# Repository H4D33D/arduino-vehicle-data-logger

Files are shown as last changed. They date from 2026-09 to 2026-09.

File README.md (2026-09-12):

# Arduino OBD-II Vehicle Data Logger

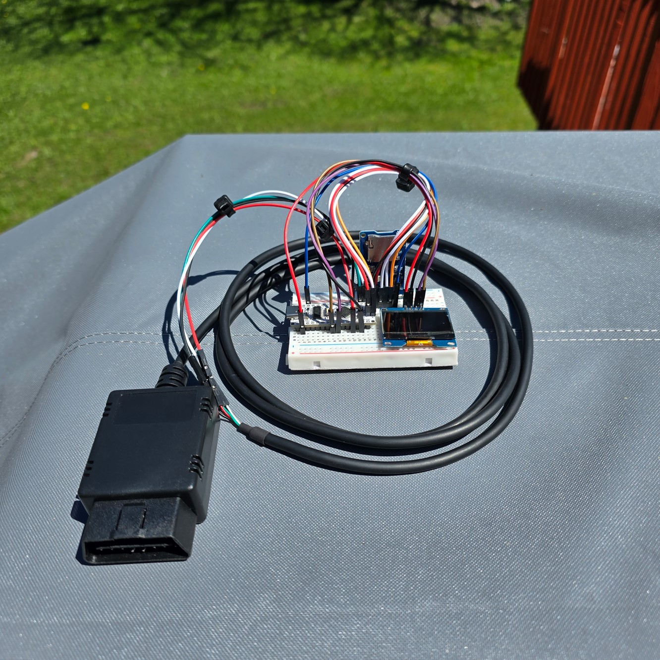
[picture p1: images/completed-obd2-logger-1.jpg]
Completed Arduino OBD-II data logger


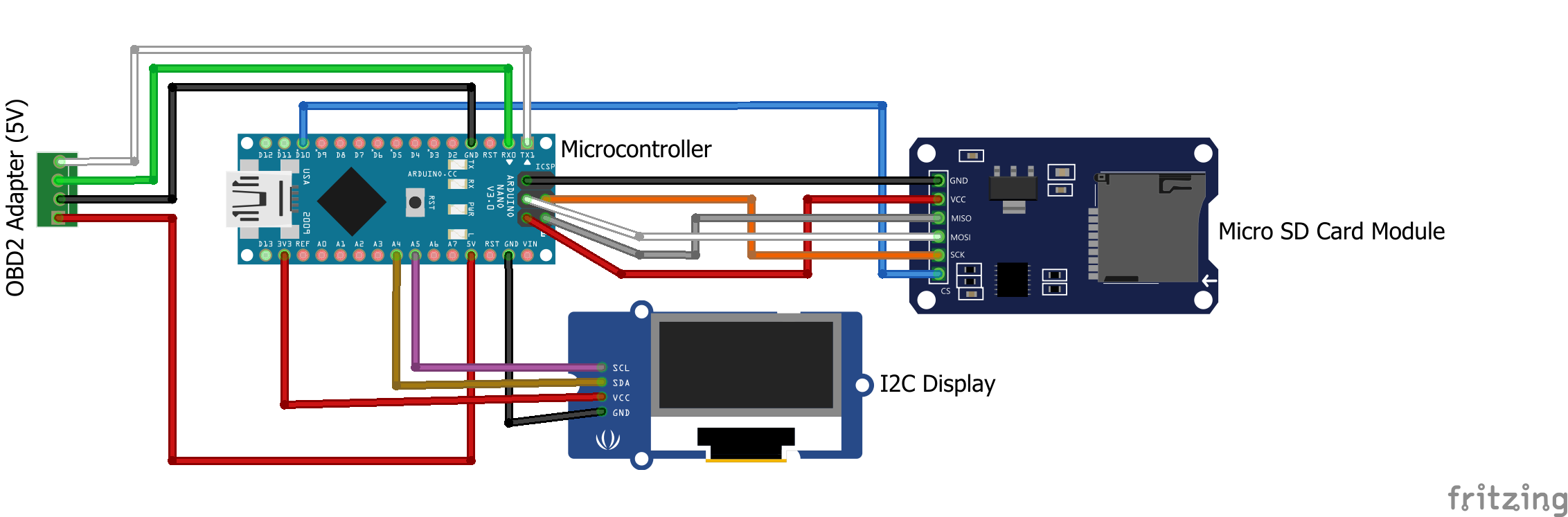
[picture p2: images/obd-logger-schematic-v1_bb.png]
OBD-II Vehicle Telemetry Logger Wiring Diagram


An embedded automotive data-logging system built with an Arduino Nano and a Freematics OBD-II UART adapter. The device reads live vehicle information, displays key parameters on an OLED screen, and records vehicle speed and engine RPM to a microSD card for later analysis.

I developed this project to combine my interests in automotive technology, embedded systems, software development, telemetry, and data analysis. I modified and optimized the Freematics reference code, resolved hardware and storage issues, restructured the logging logic, and validated the system through road testing across multiple vehicles.

This repository documents the complete project lifecycle: the [`src`](src/) directory contains the working logger code and required libraries, [`data`](data/) contains raw CSV recordings from real vehicle tests, [`graphs`](graphs/) contains annotated speed and RPM visualizations, [`images`](images/) shows the test vehicles and logger hardware during development and operation, and [`docs`](docs/) contains the detailed project notebook, wiring references, troubleshooting process, and conclusions.

## Project Highlights

- Reads real-time vehicle data through the OBD-II port
- Displays live speed, engine RPM, throttle position, and temperature data when supported by the vehicle
- Records speed and engine RPM to CSV files on a microSD card
- Operates from power supplied through the vehicle's OBD-II port
- Supports post-drive visualization and comparison in Microsoft Excel
- Was tested across vehicles from Chevrolet, Subaru, Lexus, Toyota, and Honda
- Includes documented wiring, test results, raw data, graphs, and development notes

## System Overview

The vehicle's OBD-II port supplies power and diagnostic data to the Freematics UART adapter. The Arduino Nano processes the incoming data, presents live information on the OLED display, and writes selected parameters to the SD card as CSV data. The recorded files can then be transferred to a computer and analyzed as time-series graphs.

```text
Vehicle OBD-II Port
        |
Freematics UART Adapter
        |
    Arduino Nano
      /       \
OLED Display   microSD Card
                    |
               CSV Data
                    |
             Graphs and Analysis
```

## Original Goal and Planned Expansion

In addition to building a functional data logger, I designed the project as a foundation for measuring the effects of modifications to my own car. The primary project and development vehicle was my modified **1999 Lexus GS 300**. By recording the same vehicle parameters before and after a modification, I could compare changes in speed, engine RPM, acceleration, and other supported data rather than relying only on subjective driving impressions.

I also planned to integrate the Freematics Nanotimer functionality. This would record acceleration tests such as 0-60 mph runs and preserve the results for direct before-and-after comparisons following vehicle modifications.

The longer-term hardware concept was to integrate the logger into the car's dashboard as a permanent, visible information display. My initial design would replace the right-side air vent above the center infotainment system with a custom 3D-printed enclosure containing the OLED screen and a front-facing SD card reader. This placement would keep live data visible while allowing the SD card to be removed without disassembling the dashboard.

## Hardware

- Arduino Nano
- Freematics OBD-II UART Adapter
- 128 x 64 OLED display
- 5 V-compatible microSD card module
- microSD card
- Jumper wires and breadboard
- OBD-II-compatible vehicle

## Software and Technologies

- Arduino / Embedded C++
- OBD-II vehicle diagnostics
- UART serial communication
- SPI communication
- I2C communication
- CSV data logging
- Microsoft Excel
- Data visualization and comparative analysis

## Engineering and Development Work

The available reference sketch could display live information, but its SD card logging feature was initially inactive. After enabling data logging, the program exceeded the Arduino Nano's available storage capacity.

To produce a working system, I:

- Diagnosed the disabled logging configuration in `config.h`
- Shortened nonessential OLED status messages
- Removed unused display and binary-formatting functionality
- Reduced the compiled program size from **30,820 bytes to 30,526 bytes**, bringing it below the **30,720-byte** limit
- Examined and documented the overloaded `logData` methods
- Consolidated the required logging behavior into a method focused on speed and engine RPM
- Troubleshot UART wiring, SD card compatibility, and vehicle communication
- Compared behavior across different vehicle manufacturers and model years
- Verified recorded maximum speeds against values observed during test drives

These changes preserved the core display functionality while making reliable CSV data logging possible within the Arduino Nano's memory constraints.

## Testing

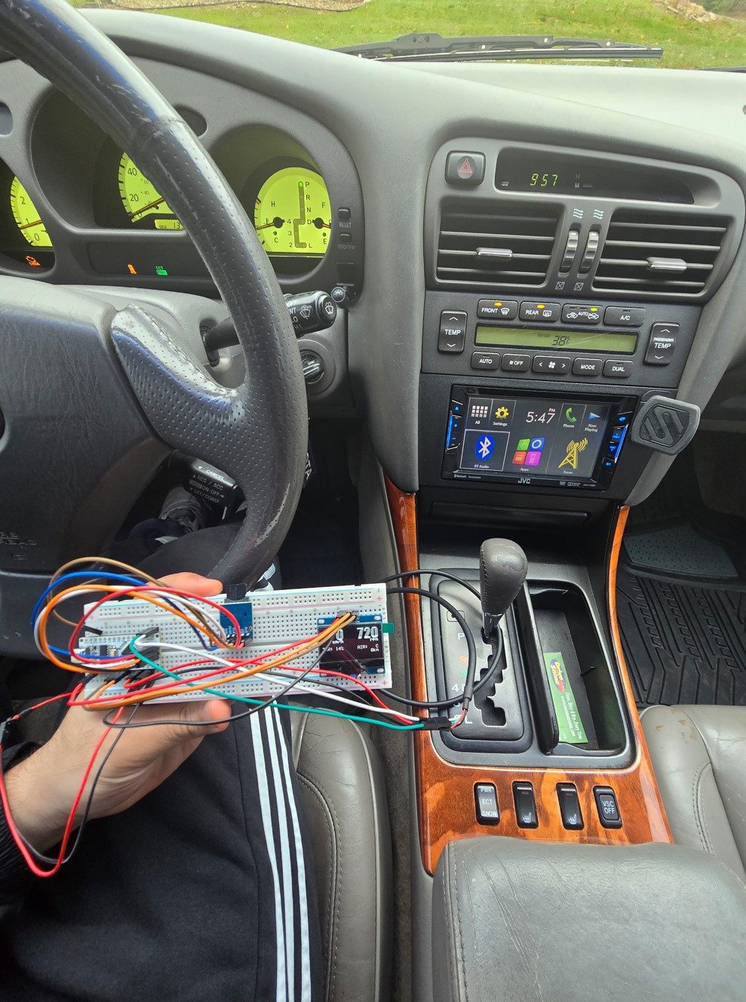
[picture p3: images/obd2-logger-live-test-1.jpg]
Data logger operating during vehicle testing


The logger was tested with several vehicles to evaluate communication reliability and data quality. Successful data collection was completed with a Chevrolet Impala, Subaru Outback, and Lexus GS 300. Additional compatibility testing was performed with Toyota, Lexus, Chevrolet, Subaru, and Honda vehicles.

Results varied between vehicles, showing the importance of testing embedded automotive systems across different manufacturers, model years, and implementations of the OBD-II standard.

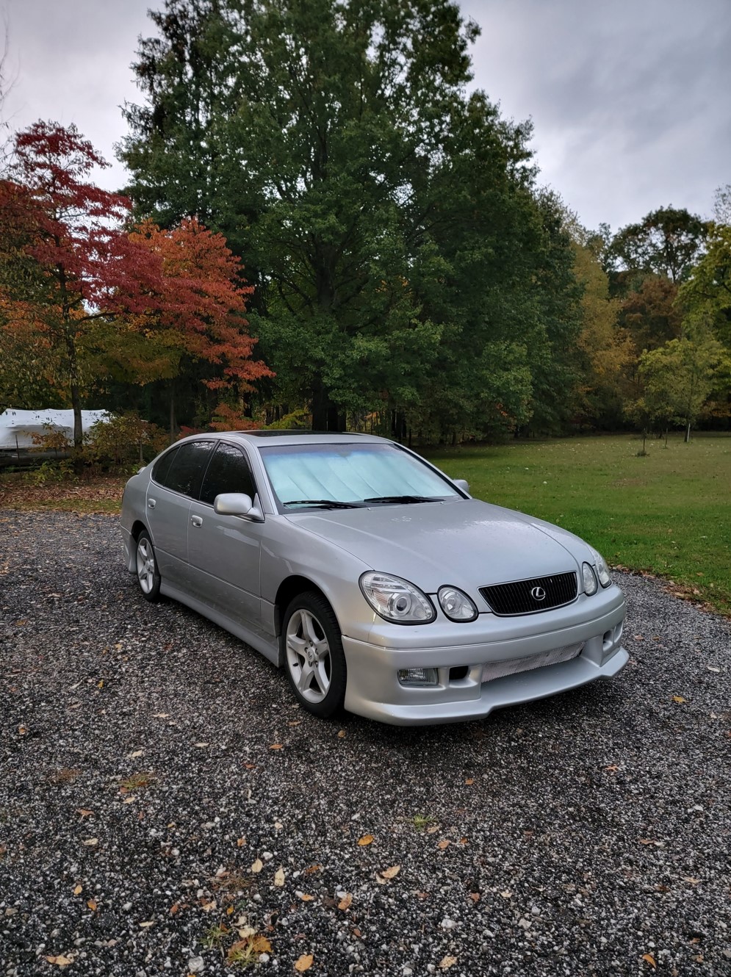
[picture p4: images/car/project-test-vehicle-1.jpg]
Vehicle used for road testing

[`Pictures Of Car`](images/car/)

## Results

Four primary driving data sets were analyzed. Across these tests:

- Average vehicle speed ranged from approximately **20 to 32 mph**
- Average engine speed ranged from approximately **1,200 to 1,700 RPM**
- The highest recorded engine-speed peak was **3,821 RPM**
- Recorded maximum speeds matched the values observed during the corresponding test drives
- The graphs showed the expected relationship between vehicle speed and engine RPM

The tests were observational rather than laboratory-controlled. Traffic, route length, idle duration, vehicle response rate, and driving conditions varied between runs.

### Example Data Visualization

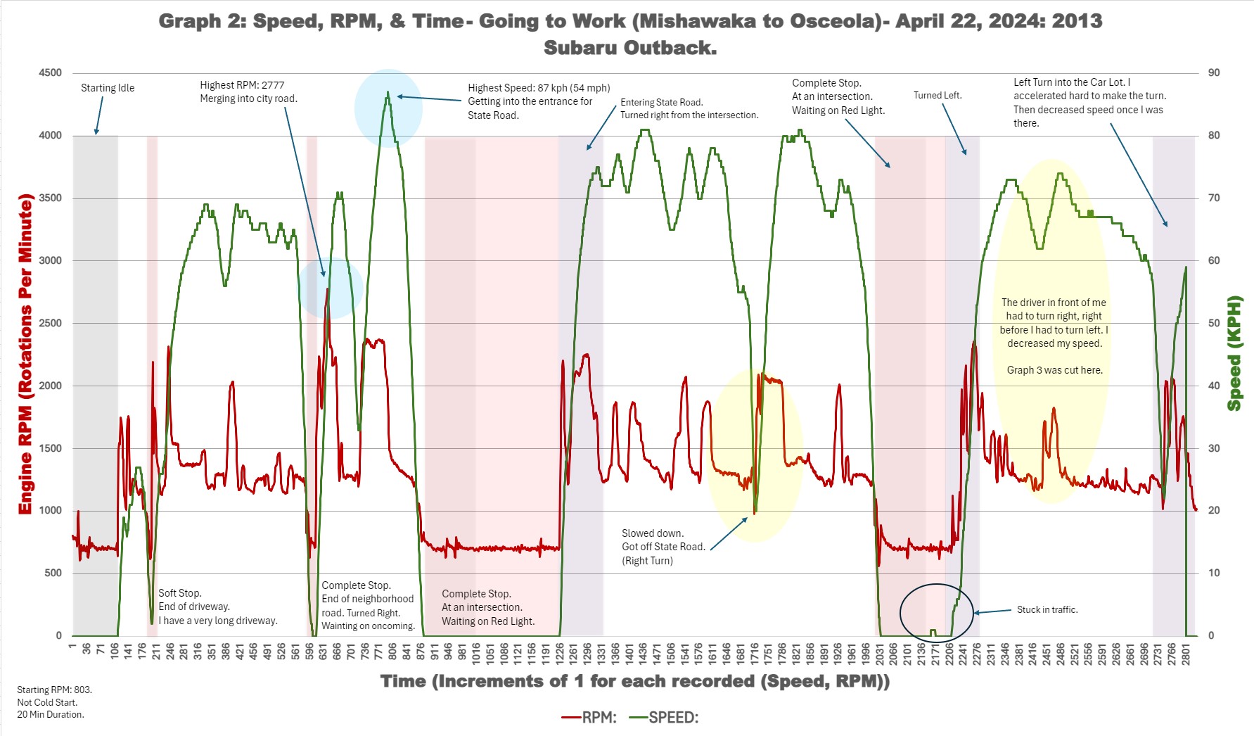
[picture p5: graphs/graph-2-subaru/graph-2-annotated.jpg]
Annotated speed and RPM graph


Additional graphs and their associated data are available in the [`graphs`](graphs/) and [`data`](data/) directories.

## Repository Structure

```text
.
├── src/
│   ├── logger/       Nanologger sketch and configuration files
│   └── libraries/    Required Arduino libraries
├── data/      Recorded CSV data from vehicle tests
├── graphs/    Annotated speed and RPM visualizations
├── images/    Hardware, vehicle, and testing photos
├── docs/      Project notebook and supporting documentation
└── README.md  Project overview
```

## Wiring Connections

The following worded schematic is based on the final working wiring configuration documented during the project.

### Freematics OBD-II UART Adapter

The adapter wires were identified by color because the individual wires were not labeled.

| Adapter wire | Arduino Nano connection |
|---|---|
| White | TX1 / D1 |
| Green | RX0 / D0 |
| Red | 5V |
| Black | GND |

If the live-data screen initializes and begins displaying vehicle information, the UART wiring is communicating correctly. If the logger remains on its welcome screen, verify the white and green serial connections.

### OLED Display

| OLED connection | Arduino Nano connection |
|---|---|
| VCC | 3.3V |
| GND | GND |
| SCL | A5 |
| SDA | A4 |

At startup, the OLED displays a welcome screen and reports the connection status of the OBD-II adapter, accelerometer, and SD card. After initialization, it displays live vehicle data.

### microSD Card Module

| SD module connection | Arduino Nano connection |
|---|---|
| CS | D10 |
| SCK | ICSP SCK |
| MOSI | ICSP MOSI |
| MISO | ICSP MISO |
| VCC | ICSP 5V |
| GND | ICSP GND |

The microSD module uses the Arduino Nano's ICSP/SPI interface. Match the connections by their signal labels—SCK, MOSI, MISO, 5V, and GND—and use the ICSP orientation diagram in the [`project notebook`](docs/) to confirm the header position. The triangle or circular orientation marker shown in the documentation should align with the Nano before power is connected.

## Running the Project

> **Safety:** Assemble and secure the hardware before driving. Do not operate or adjust the logger while the vehicle is moving. Loose wiring can disconnect during turns or acceleration.

Download or clone the **entire `src` directory**. The project depends on both `src/logger` and `src/libraries`; copying only the `.ino` file will not provide all of the files required to compile the logger.

1. Install the Arduino IDE.
2. Add the included `src/libraries` directory to the Arduino environment, or copy its contents into the Arduino libraries directory.
3. Connect the OBD-II adapter, OLED display, and SD card module according to the wiring documentation in [`docs`](docs/).
4. Open `src/logger/nanologger.ino` in the Arduino IDE.
5. Select the correct Arduino Nano board and processor settings.
6. Compile and upload the sketch.
7. Connect the adapter to an OBD-II-compatible vehicle manufactured in 1996 or later.
8. Start the vehicle and confirm that the display reports successful OBD-II and SD card initialization.
9. After testing, remove the microSD card and open the generated CSV file on a computer for analysis.

## Documentation

The [`docs`](docs/) directory contains the complete development notebook, including:

- Initial research and planning
- Wiring details and diagrams
- Troubleshooting notes
- Program-memory optimization
- Vehicle compatibility observations
- Test results and graphs
- Conclusions and proposed improvements

## Future Improvements

- Store both km/h and mph consistently in the output data
- Record additional parameters such as engine temperature, distance traveled, and selected gear when supported
- Add stronger protection against interrupted or incomplete data writes
- Integrate the Nanotimer functionality to record acceleration tests and compare performance before and after vehicle modifications
- Build a compact 3D-printed dashboard enclosure with an integrated display and front-facing SD card reader
- Evaluate replacing the right-side air vent above the center infotainment system with the custom enclosure
- Secure the hardware for repeatable in-vehicle testing
- Conduct controlled tests using the same route and driving conditions
- Automate CSV processing and graph generation

## What This Project Demonstrates

This project demonstrates practical experience with:

- Embedded software development
- Automotive systems and OBD-II diagnostics
- Hardware integration and wiring
- Debugging under memory and storage constraints
- Serial and peripheral communication
- Iterative testing across real-world systems
- Technical documentation
- Data collection, visualization, and interpretation

## Acknowledgments

This project uses and modifies reference code and libraries provided by [Freematics](https://freematics.com/). The implementation, configuration, optimization, testing, documentation, and data analysis in this repository reflect my project work. Any third-party source files retain their original ownership and licensing requirements.

## Author

**Hadeed Fawad**  
Computer Science graduate interested in software engineering, embedded systems, automotive technology, data analysis, and technical problem-solving...

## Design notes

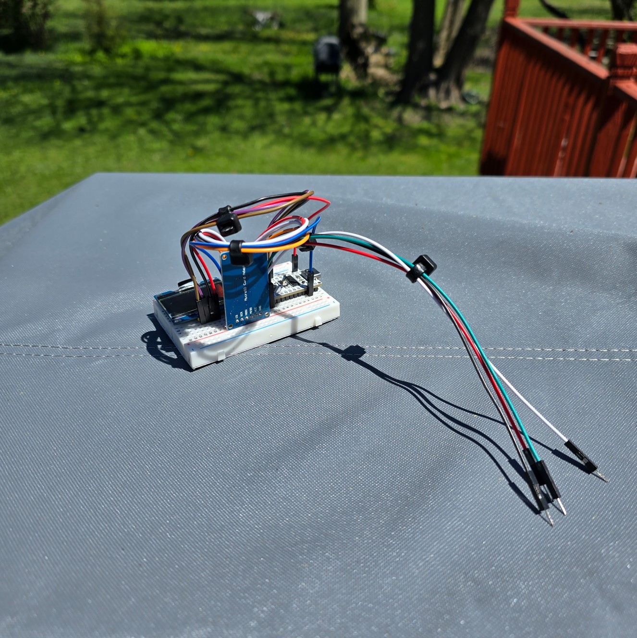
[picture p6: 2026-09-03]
images/completed-obd2-logger-3.jpg

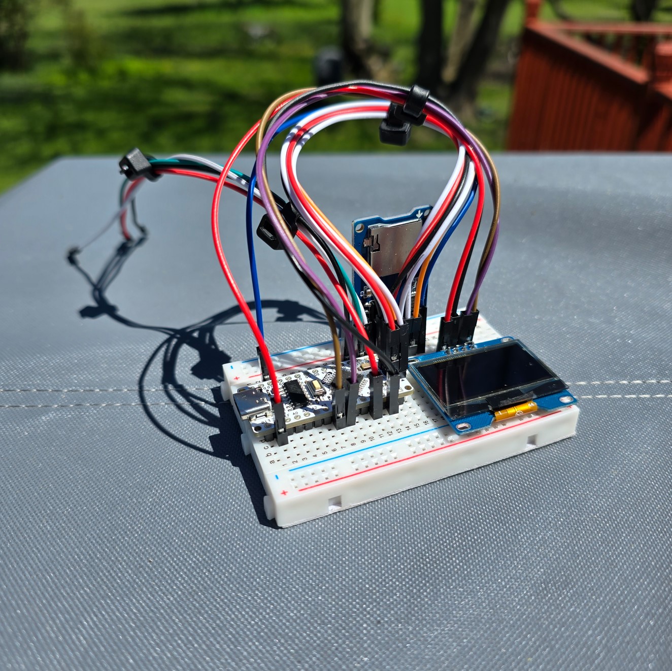
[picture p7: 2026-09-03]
images/completed-obd2-logger-2.jpg

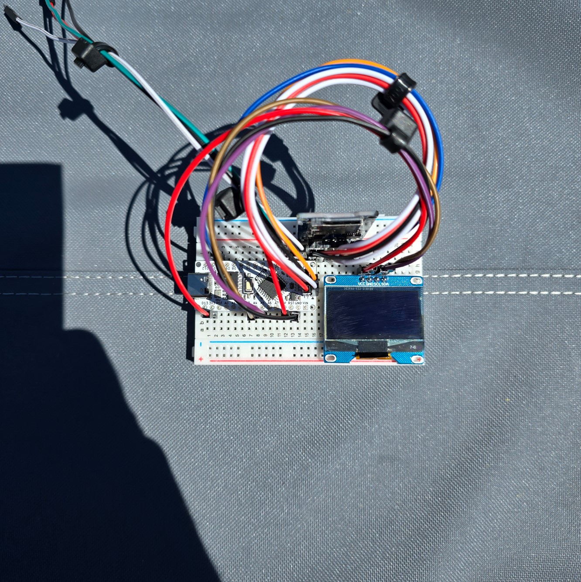
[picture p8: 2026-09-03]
images/completed-obd2-logger-4.jpg

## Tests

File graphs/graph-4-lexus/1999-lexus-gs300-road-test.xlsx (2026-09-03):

TIME: | SPEED: | RPM:
1 | 0 | 1482
2 | 0 | 1489
3 | 0 | 1494
4 | 0 | 1510
5 | 0 | 1025
6 | 0 | 1014
7 | 0 | 1011
8 | 0 | 1012
9 | 0 | 960
10 | 0 | 968
11 | 0 | 964
12 | 0 | 964
13 | 0 | 1542
14 | 10 | 1614
15 | 12 | 1556
16 | 14 | 1575
17 | 16 | 949
18 | 27 | 937
19 | 26 | 925
20 | 25 | 916
21 | 24 | 2310
22 | 20 | 2239
23 | 24 | 2335
24 | 28 | 2504
25 | 31 | 2028
26 | 57 | 2021
27 | 57 | 1971
28 | 57 | 1955
29 | 57 | 751
30 | 5 | 722
31 | 0 | 732
32 | 0 | 727
33 | 0 | 710
34 | 0 | 710
35 | 0 | 714
36 | 0 | 711
37 | 0 | 2489
38 | 67 | 2514
39 | 69 | 2525
40 | 70 | 2519
41 | 71 | 1310
42 | 64 | 1284
43 | 63 | 1284
44 | 63 | 1260
45 | 62 | 2353
46 | 48 | 2417
47 | 52 | 2479
48 | 55 | 2625
49 | 56 | 3085
50 | 113 | 3117
51 | 115 | 3140
52 | 116 | 3156
53 | 117 | 2892
54 | 127 | 3271
55 | 126 | 3297
56 | 127 | 2631 |  | Speed: | Rpm:
57 | 109 | 2435 | Max: | 127 | 3297
58 | 99 | 2446 | Average: | 53.18378378 | 1667.232432
59 | 99 | 2460
60 | 100 | 2470
61 | 100 | 2165
62 | 88 | 2154
63 | 87 | 1810
64 | 86 | 1693
65 | 86 | 2540
66 | 87 | 2582
67 | 88 | 2625
68 | 90 | 2631
69 | 91 | 1762
70 | 88 | 1718
71 | 87 | 1666
72 | 86 | 1622
73 | 84 | 1928
74 | 44 | 1928
75 | 46 | 1961
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

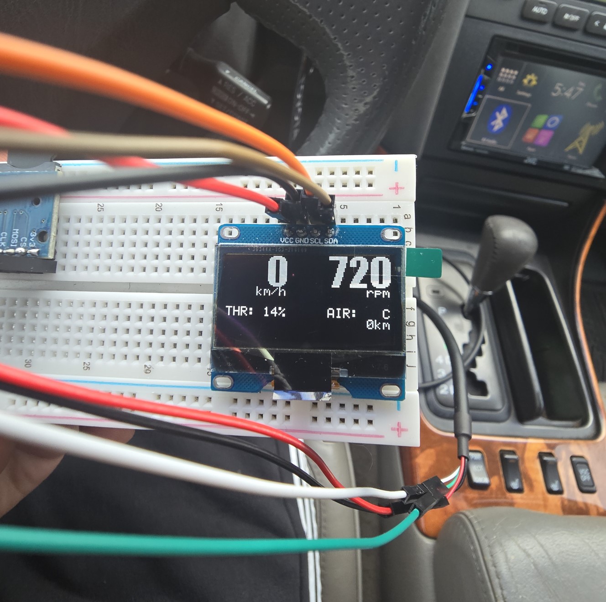
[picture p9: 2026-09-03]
images/obd2-logger-live-test-2.jpg

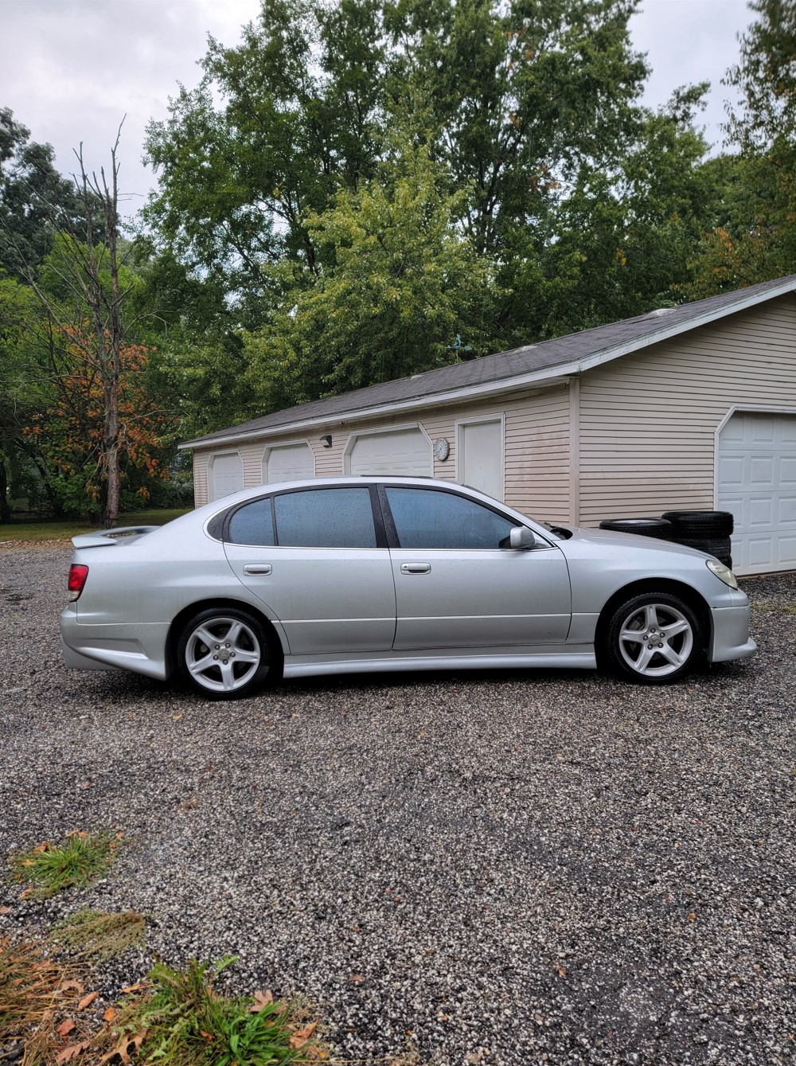
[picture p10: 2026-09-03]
images/car/project-test-vehicle-3.jpg

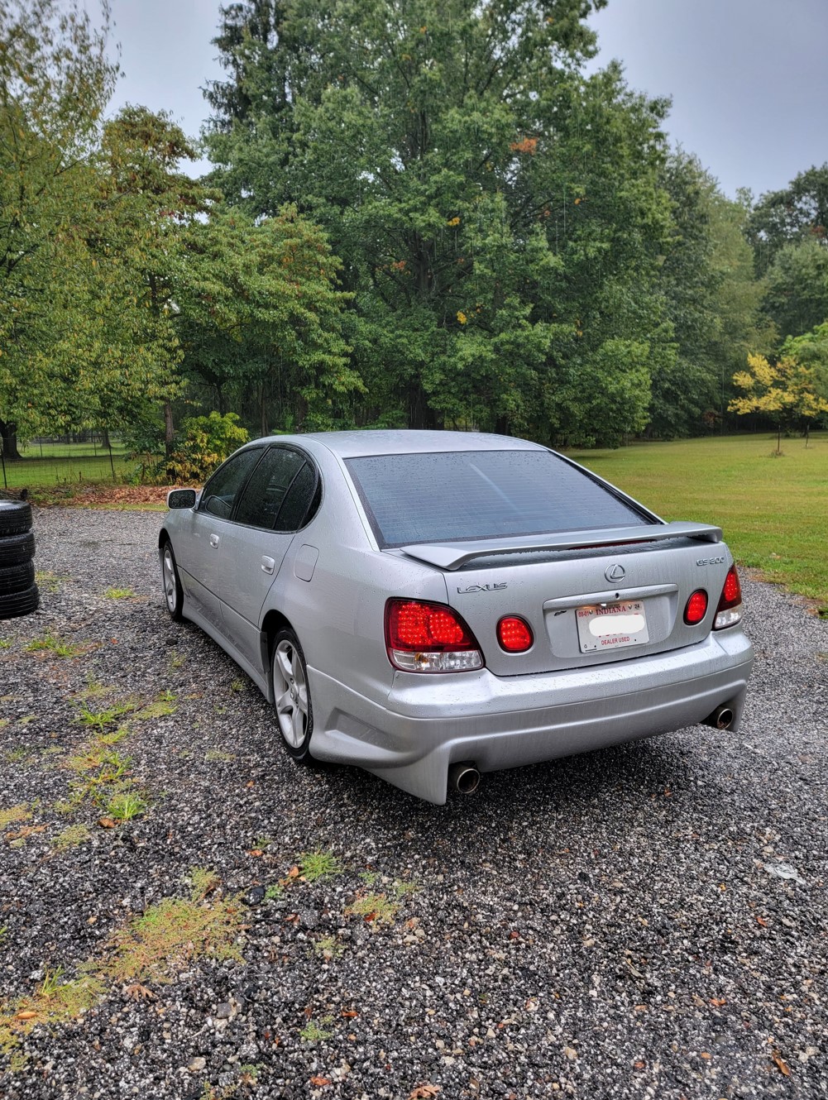
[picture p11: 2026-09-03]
images/car/project-test-vehicle-2.jpg

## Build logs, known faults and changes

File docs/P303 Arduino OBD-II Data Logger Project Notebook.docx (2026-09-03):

P303 Arduino OBD-II Data Logger Project Notebook

Initial Research:

Forums (https://forum.arduino.cc/t/arduino-vehicle-obd-ii-data-logger/144246)

Store / Product Purchased (https://freematics.com/store/index.php?route=product/product&product_id=74)

Download (https://sourceforge.net/projects/obdcon/)

GitHub Instructions (https://github.com/stanleyhuangyc/ArduinoOBD)

https://freematics.com/pages/products/arduino-telematics-kit-1/

2/18/24 @ 5 PM - Ordered the Freematics OBD-II Kit, which ships from Australia. No delivery estimate was available at the time, but forum discussions suggested that orders typically ship within one or two days and arrive within approximately two weeks.

Important note: The kit is designed for vehicles manufactured in 1996 or later that support OBD-II.

02/23/24 @ 8 PM - According to USPS tracking, the OBD-II Kit has reached Chicago and is arriving sooner than expected.

02/27/24 @ 5 PM - OBD2 Kit has arrived.

Note: The initial objective was to test the kit as a standalone system before attempting to integrate it with the course-provided board.

PART 2: Initial Testing / Planning

Spring Break - Initial standalone testing began with the goal of verifying the kit's basic functionality.

Pin Wiring Set Up:

OBD-II Adapter: Red = VCC, Black = GND, White = TX, and Green = RX.

LCD Display: VCC, GND, SDA, SCL

Important note: The Arduino receives power through the vehicle's 12 V OBD-II port. The adapter converts this input to 5 V for the connected device.

Note: The DS18B20 temperature sensor provided in Lab 5 was tested successfully.

Note: The project can read engine and transmission diagnostic trouble codes.

Data available through the OBD-II adapter (based on the Freematics documentation):

Units vary by parameter and vehicle configuration.

Engine RPM (rpm)

Calculated engine load (%)

Engine coolant temperature (°C)

Absolute Engine load (%)

Ignition timing advance (°)

Engine oil temperature (°C)

Engine torque percentage (%)

Engine reference torque (Nm)

Intake temperature (°C)

Intake manifold absolute pressure (kPa)

MAF flow pressure (grams/s)

Barometric pressure (kPa)

Vehicle speed (km/h)

Engine running time (second)

Vehicle running distance (km)

Throttle position (%)

Ambient temperature (°C)

Vehicle control module voltage (V)

Hybrid battery pack remaining life (%)

libraries - Arduino libraries required by the OBD-II adapter and kit

- samples - Simple sketches for initial testing
- nanologger - OBD-II data logger for an Arduino Nano with a 128 x 64 monochrome OLED display; selected as the foundation for this project
- megalogger - OBD-II and GPS data logger for an Arduino Mega with a 320 x 240 TFT LCD
- megaloggerHD - OBD-II and GPS data logger for an Arduino Mega with a 480 x 320 TFT LCD
- tester - Test sketch for OBD-II communication and supported parameters
- utilities - Supporting utility source code

3/28/24 - Communication Testing

Upload the program to the Arduino Pro Mini, connect the Arduino to the laptop and the OBD-II adapter to the running vehicle, then open the Serial Monitor to verify communication between the vehicle and the Arduino.

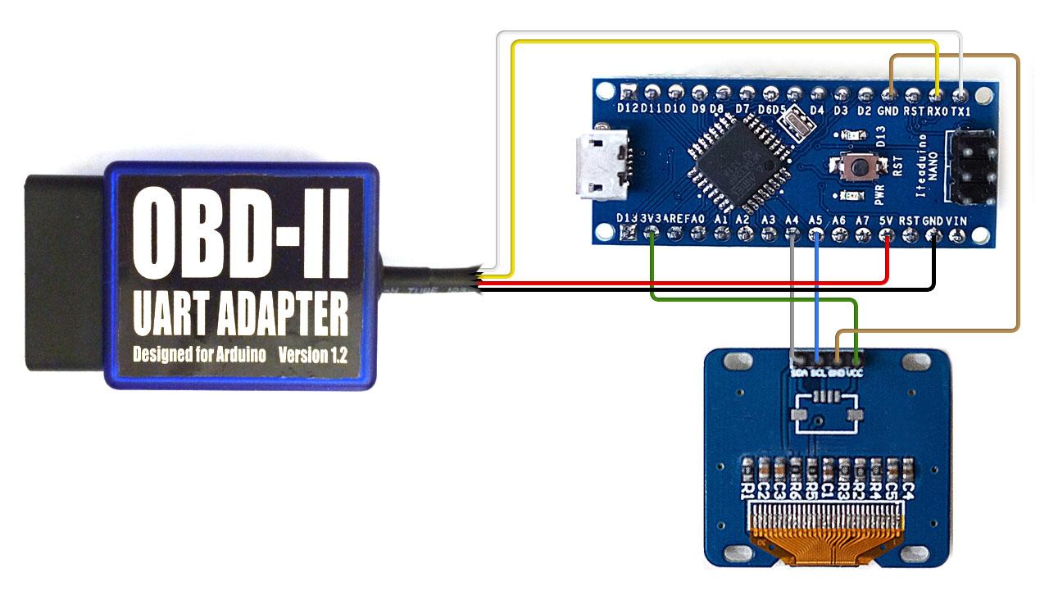
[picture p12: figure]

4/2/24 - Data logging was still not working. The next step was to remove the three pins from the course-provided Nano and solder the six ICSP pins onto the replacement board. The nanologger configuration requires the SD card module to connect through the ICSP interface.

Nanotimer - Measures vehicle acceleration from 0-60, 0-80, and 0-100.

Nanologger - Displays real-time vehicle data and records it to an SD card.

April 4, 2024 @ 9:48 AM - Initial testing confirmed that the wiring was correct: the OBD-II adapter received power from the vehicle and displayed live data. However, the SD card logging function was still not working, so I ordered a 5 V-compatible SD card module to eliminate a possible voltage-compatibility issue.

Next troubleshooting step: verify the RX and TX connections.

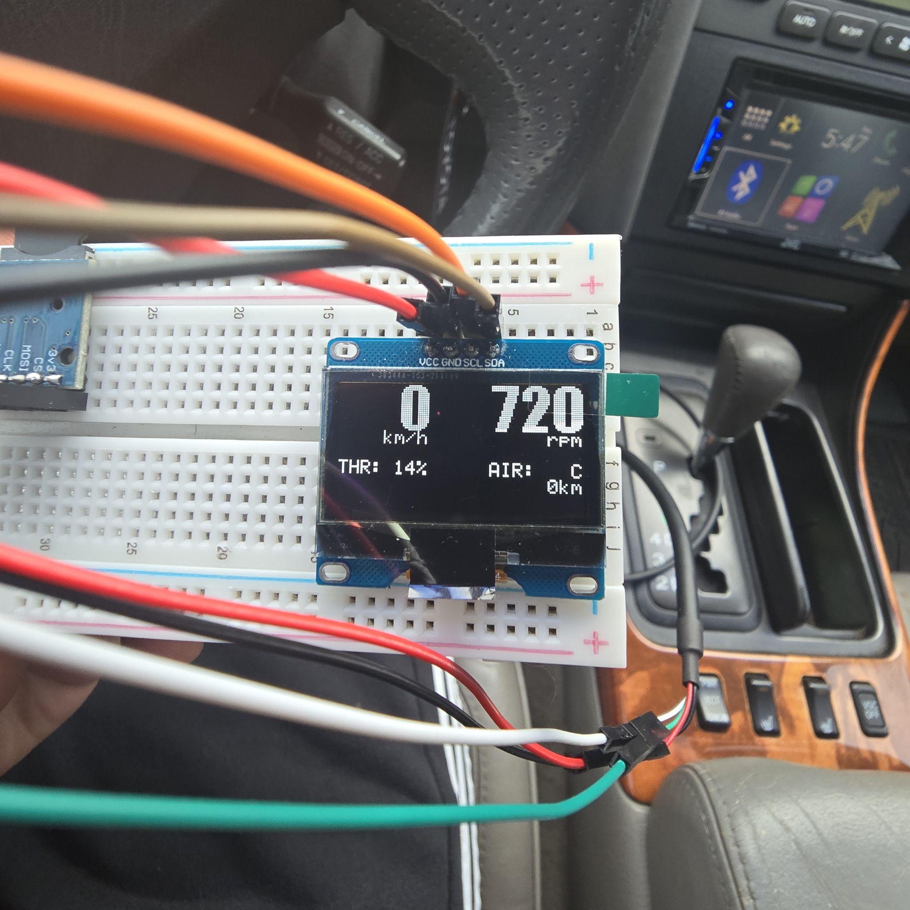
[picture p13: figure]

- Communication testing was unsuccessful with three Honda vehicles (2008 Accord, 2007 Civic, and 2008 Pilot). Successful tests were completed with Toyota vehicles (2010 RAV4 and 2008 Camry), Lexus vehicles (1999 GS 300 and 2010 RX 300), a 2006 Chevrolet Impala, and a 2013 Subaru Outback. The Chevrolet produced the most consistent initial results.
- Vehicle speed was reported in km/h even when the vehicle used imperial units. I added a conversion for the on-screen mph display, but the recorded CSV values continued to use km/h.
- Access to several vehicles made it possible to compare compatibility and data output across different manufacturers and model years.

Part 3: Code Optimization and Extended Testing

I paused notebook updates during the extended testing phase while I analyzed the Freematics reference code. Although the LCD displayed live data, the SD card logging functionality was initially inactive. In config.h, I discovered that #define ENABLE_DATA_LOG was set to 0. After enabling it, the compiled sketch exceeded the Arduino's available program storage by approximately 500 bytes. Because display strings consume program memory, I shortened several LCD messages and removed nonessential display functionality while preserving the system's core real-time monitoring and logging features.

Examples of shortened display messages (default -> revised):

- (“No Log”) → (“F1”);
- (“No Fat SD”) → (“F2”);
- (“Bad SD”) → (“F3”);
- (“Reconnecting”); → (“...”);

Using compact numbered failure codes reduced the message storage requirement from approximately 50 bytes to 6 bytes, in addition to the savings from other shortened display strings.

Removing the following SD card type-detection and display block saved approximately 30 bytes:

if (card.init(SPI_FULL_SPEED, SD_CS_PIN)) {

const char* type;

lcd.print("SD");

switch(card.type()) {

case SD_CARD_TYPE_SD1:

type = "1";

break;

case SD_CARD_TYPE_SD2:

type = "2";

break;

case SD_CARD_TYPE_SDHC:

type = "HC";

break;

default:

type = "x";

}

lcd.print(type);

lcd.write(' ');

if (!volume.init(card)) {

lcd.print("No FAT");

return false;

}

Removing the following distance-traveled display block from the main loop saved approximately 100 bytes:

char buf[10];

sprintf(buf, "%4ukm", (uint16_t)(distance / 1000));

lcd.setFontSize(FONT_SIZE_SMALL);

lcd.setCursor(92, 6);

lcd.print(buf);

I also removed code used to format data as binary values. These changes provided the remaining program-space savings needed for compilation. The source files contain comments identifying the sections that were added, changed, or removed.

After reducing the program size while preserving the LCD functionality, the first road test successfully created a file on the SD card. The recorded output was not yet structured as expected, although the values appeared to repeat in consistent four-line groups. I then examined datalogger.h, added section dividers and explanatory comments, and reviewed its five overloaded logData methods. Each method recorded a different group of parameters. I consolidated the required functionality into a single method focused on vehicle speed and engine RPM, producing a clearer CSV output for analysis.

Vehicle availability affected the testing schedule. A 2008 Honda Accord did not advance beyond the welcome screen, which initially led to additional troubleshooting of the hardware and code. Testing across other manufacturers showed that the same setup worked reliably with a Subaru, allowing development and validation to continue.

Compatibility varied by manufacturer and model. The tested Toyota and Lexus vehicles communicated reliably with the kit, as did the Subaru, while the tested 2004-2008 Honda vehicles did not. These observations are limited to the specific vehicles tested and do not establish compatibility for every model from those manufacturers.

The final optimization reduced the compiled program size from 30,820 bytes to 30,526 bytes, bringing it below the 30,720-byte limit and allowing the sketch to compile successfully. I also reorganized and documented the code and configured the logger to record vehicle speed and engine RPM. Potential future parameters include selected gear, distance traveled, and engine temperature, which could support broader comparisons among vehicles.

Part 4: Final Implementation

Final working wiring configuration:

OBD-II Adapter: The adapter wires are identified by color rather than printed labels. The white and green wires carry TX and RX signals. A successful live-data display confirms that the serial connections are oriented correctly.

- White Cable = Tx1 Pin
- Green Cable = RX0 Pin
- Red Cable = 5v Pin
- Black cable = GND Pin

LCD Screen: At startup, the display shows a welcome screen and reports the connection status of the OBD-II adapter, accelerometer, and SD card. After initialization, it displays live vehicle speed, engine RPM, the amount of data recorded, throttle position, and engine temperature. Parameter availability may vary by vehicle.

- VCC = 3v3 Pin
- GND = GND Pin
- SCL = A5 Pin
- SDA = A4 Pin

SD Card Module: Uses the ICSP interface. Orient the Arduino Nano as shown in the diagram before matching the following pins:

- CS = D10 Pin
- SCK = ICSP Pin 2 (SCK)
- MOSI = ICSP Pin 3 (MOSI)
- MISO = ICSP Pin 5 (MISO)
- VCC = ICSP Pin 6 (5 V)
- GND = ICSP Pin 4 (GND)
- Testing indicated that the logger could be disconnected safely before the data buffer reached 1,024 bytes; the source code provides additional context for the write process.
- I created the following wiring diagram as a reference for assembly and future troubleshooting.

Align the ICSP header and the triangle (or circular) orientation marker with the Arduino Nano as shown.

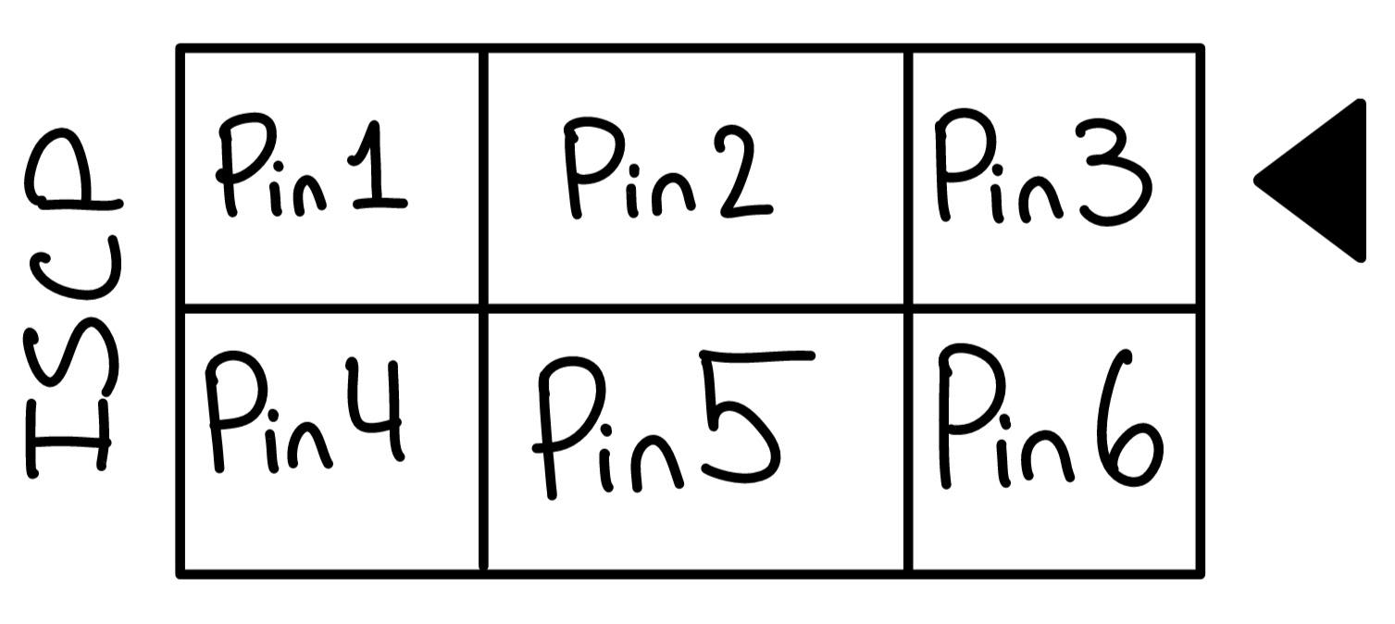
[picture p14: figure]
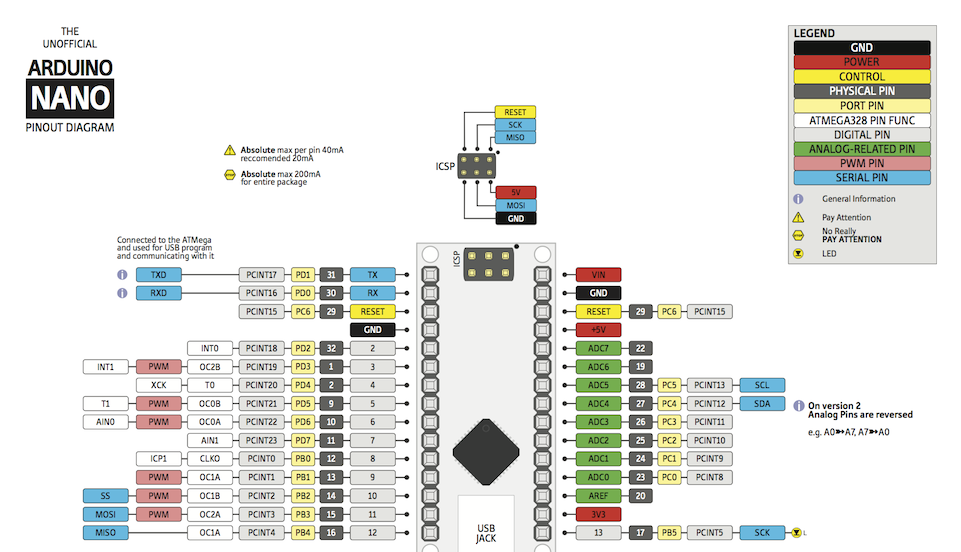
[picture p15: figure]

Photos of the Completed Data Logger

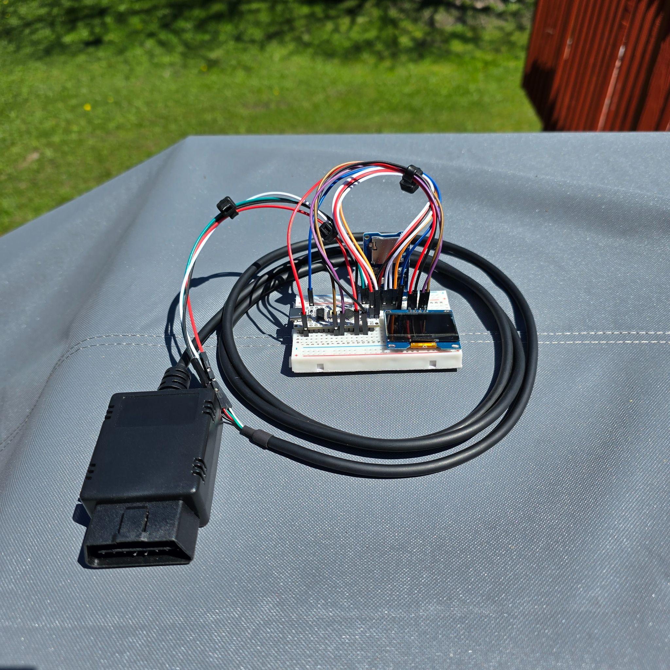
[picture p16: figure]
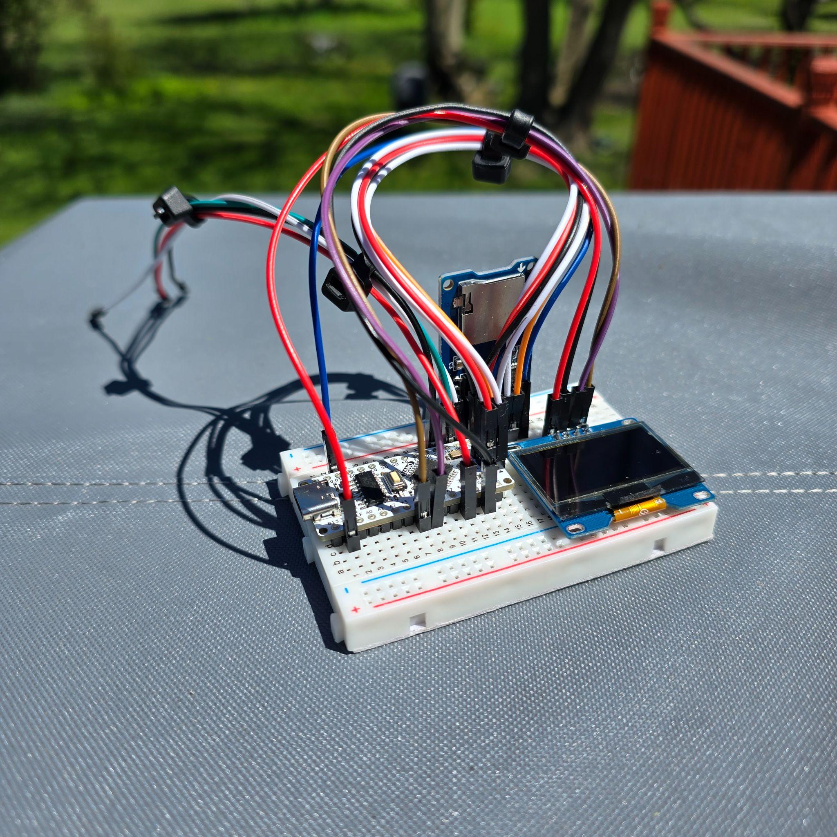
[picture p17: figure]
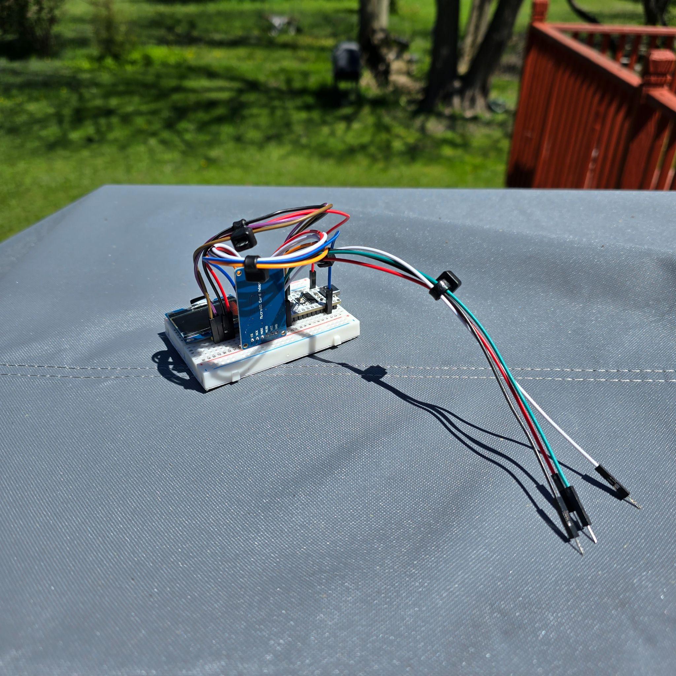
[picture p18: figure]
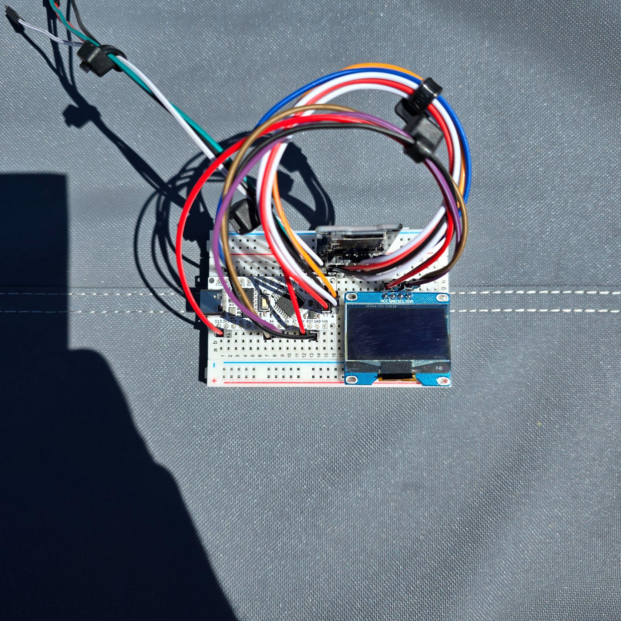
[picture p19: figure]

Graphs:

- The following annotated graphs summarize the recorded speed and engine RPM data. Full-resolution graph images are included with the project files.

Graph 1: Link. (https://indiana-my.sharepoint.com/:x:/g/personal/hafawad_iu_edu/EbbKNxPulxZBnqzmiVfoBncB2XoYConjS2-Qc2u3y7ooZA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)

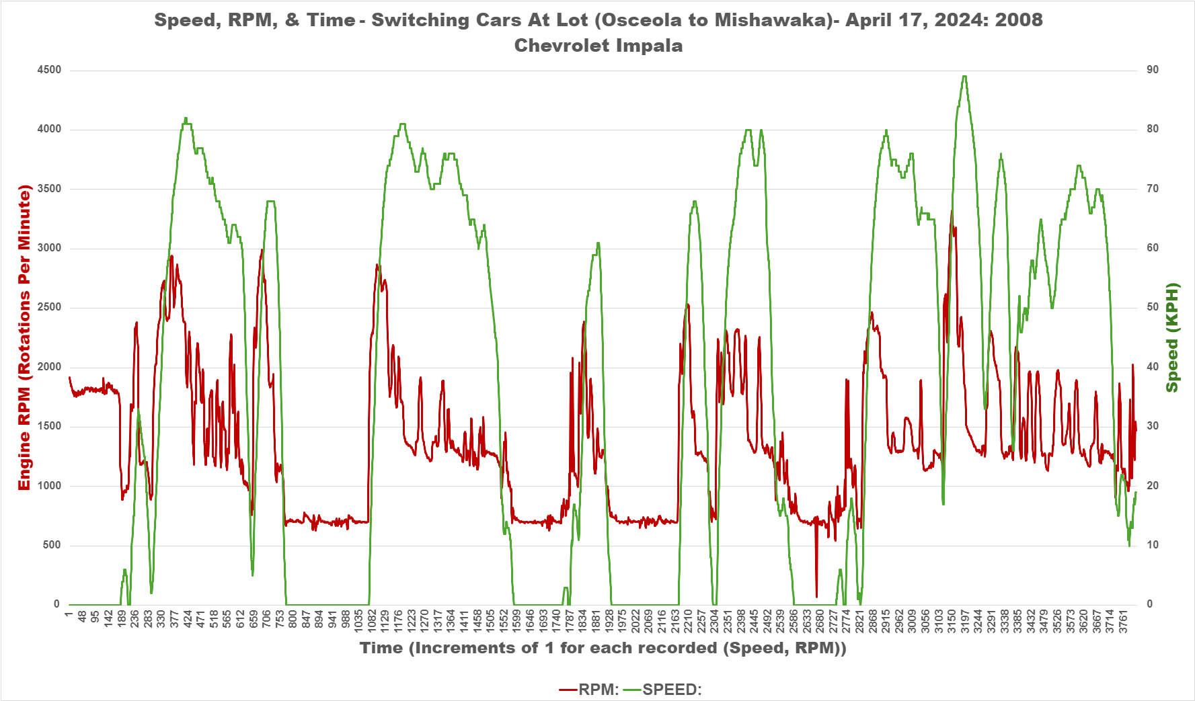
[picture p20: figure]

Graph 1: | Speed: | Rpm:
Max: | 89 kph (55 mph) | 3324
Average: | 37 kph (23 mph) | 1392

Graph 2: Link. (https://indiana-my.sharepoint.com/:x:/g/personal/hafawad_iu_edu/EXIUqGPP5TlPqpYHcEwPdk8BFYKwMSWuBbSc1q8c_Tq0Ew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)

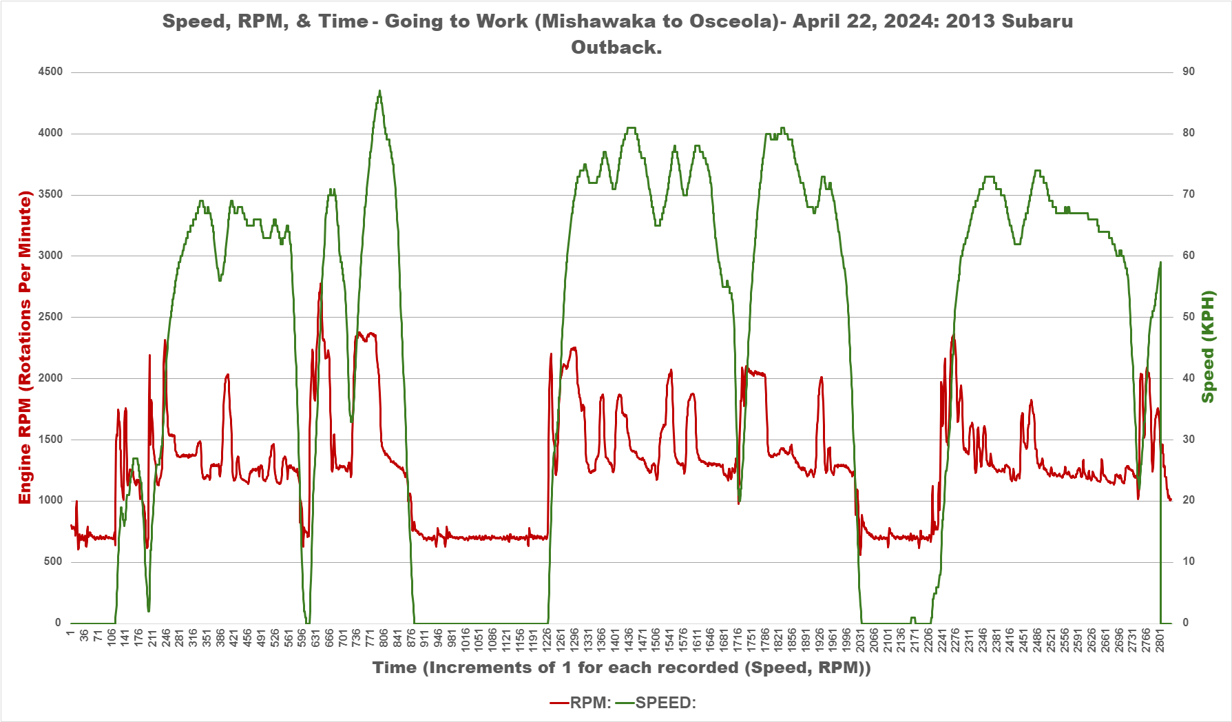
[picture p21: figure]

Graph 2: | Speed: | Rpm:
Max: | 87 kph (54 mph) | 2777
Average: | 44 kph (27 mph) | 1284

Graph 3: Link. (https://indiana-my.sharepoint.com/:x:/g/personal/hafawad_iu_edu/ET9qlVQFwMdGqdeKRJn17BcBtiWTOnC392jfO0L6VO3ObA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)

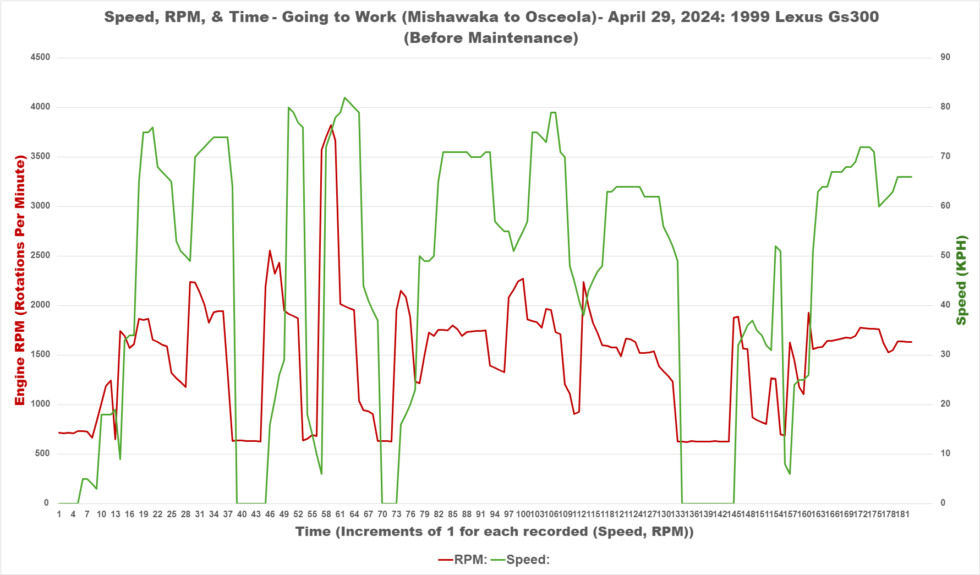
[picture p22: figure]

Graph 3: | Speed: | Rpm:
Max: | 82 kph (51 mph) | 3821
Average: | 45 kph (28 mph) | 1476

Graph 4: Link. (https://indiana-my.sharepoint.com/:x:/g/personal/hafawad_iu_edu/EVPHjInuHspHj0aNwztyMN0BiZY_Tmh384_w5ckoLnHeeg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)

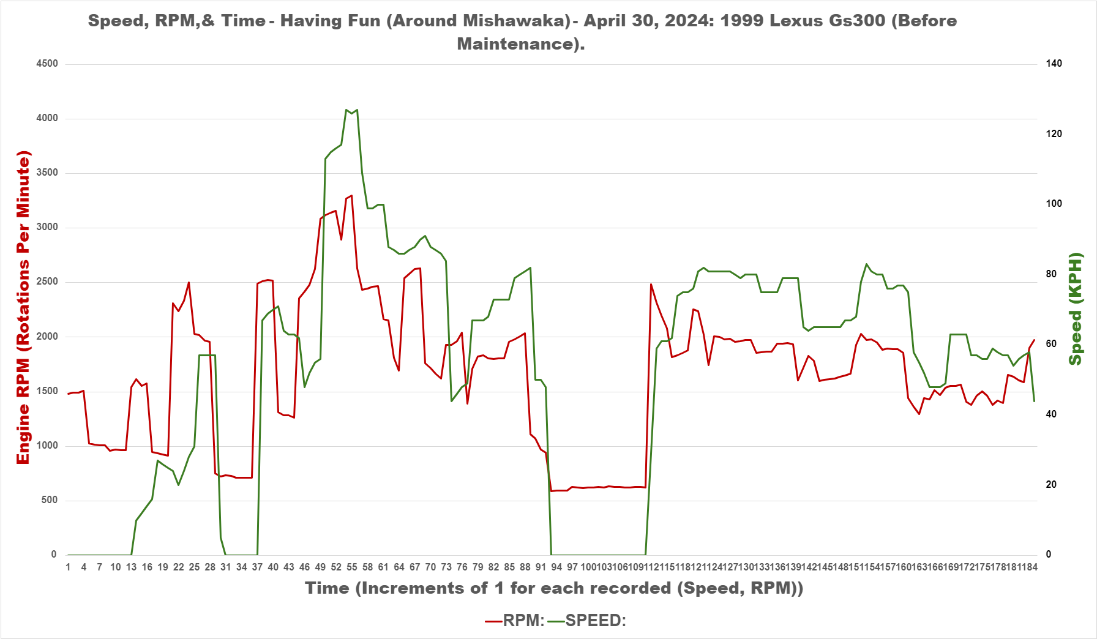
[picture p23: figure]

Graph 4: | Speed: | Rpm:
Max: | 127 kph (80 mph) | 3297
Average: | 53 kph (32 mph) | 1667

- Across the four data sets, average vehicle speed remained between approximately 20 and 32 mph.
- Average engine speed remained between approximately 1,200 and 1,700 RPM, while the maximum values were generally near 3,000 RPM. Graph 3 recorded the highest engine-speed peak at 3,821 RPM.

Graph 1 represents a trip beginning after work and continuing through several additional stops.

Graphs 2 and 3 have similar overall shapes because both data sets were recorded while traveling to work, although Graph 3 contains a shorter recording. Graph 2 contains substantially more samples than Graph 3. Differences in sampling totals and graph shape may reflect vehicle-specific response rates, traffic signals, traffic flow, speed, initial idle duration, trip length, and time of day. Because these conditions were not controlled, the graphs should be interpreted as observational comparisons rather than identical test runs.

The Lexus GS 300 produced the highest average engine RPM of the tested vehicles. This may indicate higher engine speed under similar driving conditions, but additional controlled testing would be required before drawing conclusions about fuel economy or maintenance needs. Its observed warm-idle speed was approximately 714 RPM, compared with approximately 803 RPM for the Subaru. The maximum speeds recorded by the logger matched the values observed during each test drive, and the expected relationship between speed and engine RPM was visible across the graphs. These comparisons support the logger's general accuracy while also identifying the need for repeatable routes and controlled driving conditions in future testing.

Important note: Secure all wiring and components before driving. Hard turns or acceleration can loosen the connections between the kit and the OBD-II adapter.

Conclusion and Future Work

The related Nanotimer program could support future before-and-after comparisons of vehicle acceleration following modifications.

The analysis phase also strengthened my ability to organize, visualize, and interpret recorded data in Microsoft Excel.

A future hardware improvement would be a compact 3D-printed enclosure for the Arduino, display, SD card module, and wiring. A small vent-mounted design could keep the unit accessible while reducing movement during a test drive.

This project combined two of my interests: automotive technology and computer science. I transformed partially functioning reference code into a working OBD-II data logger by troubleshooting serial communication and SD card output, reducing memory usage, restructuring the logging logic, and validating the results across multiple vehicles. Future improvements could include consistent mph output, protection against incomplete data writes, additional vehicle parameters, a compact enclosure, and more controlled comparative testing.

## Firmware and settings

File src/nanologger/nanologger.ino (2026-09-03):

//P303 Final Project
//Hadeed Fawad
//Mainly for LCD Screen functionaity, and calls datalogger.h for data. 

#include <Arduino.h>
#include <Wire.h>
#include <SPI.h>
#include <SD.h>
#include <OBD2UART.h>
#include <MicroLCD.h>
#include "images.h"
#include "config.h"
#if USE_SOFTSERIAL
#include <SoftwareSerial.h>
#endif
#include "datalogger.h"


//-----------------------------------
// logger states


#define STATE_SD_READY 0x1
#define STATE_OBD_READY 0x2
#define STATE_GPS_FOUND 0x4
#define STATE_GPS_READY 0x8
#define STATE_ACC_READY 0x10
#define STATE_SLEEPING 0x20


//----------------------------------
//Variable, Values, Arrays Declaration.


static uint32_t lastFileSize = 0;
static int lastSpeed = -1;
static int speed = 0;
static uint16_t fileIndex = 0;
static uint32_t startTime = 0;


static byte pidTier1[]= {PID_RPM, PID_SPEED, PID_ENGINE_LOAD, PID_THROTTLE};
static byte pidTier2[] = {PID_INTAKE_MAP, PID_MAF_FLOW, PID_TIMING_ADVANCE};


#define TIER_NUM1 sizeof(pidTier1)
#define TIER_NUM2 sizeof(pidTier2)


byte pidValue[TIER_NUM1];


//--------------------------------------------------
//Main Class


class COBDLogger : public COBD, public CDataLogger
{


public:
    COBDLogger():state(0) {} //Show Start up screen
    void setup()
    {
        showStates();


        do {
            showStates();
        } while (!init());


        state |= STATE_OBD_READY;


        showStates();


#if ENABLE_DATA_LOG
        uint16_t index = openFile();
        lcd.setFontSize(FONT_SIZE_SMALL);
        lcd.setCursor(86, 0);
        if (index) {
            lcd.write('[');
            lcd.setFlags(FLAG_PAD_ZERO);
            lcd.printInt(index, 5);
            lcd.setFlags(0);
            lcd.write(']');
        } else {
            lcd.print("F1"); //NO LOG - F represents a Failure
            //having these failures identitfiable with integers costs 6 bytes. But saves alot more.
        }
        delay(100);
#endif


#if ENABLE_DATA_LOG
        // open file for logging
        if (!(state & STATE_SD_READY)) {
            if (checkSD()) {
                state |= STATE_SD_READY;
                showStates();
            }
        }
#endif


        initScreen();


    } //end of public: COBDLogger()


    void loop()
    {
        static byte index = 0;
        static byte index2 = 0;
        static byte index3 = 0;


        // poll OBD-II PIDs
        logOBDData(pidTier1[index++]);
        if (index == TIER_NUM1) {
            index = 0;
            if (index2 == TIER_NUM2) {
                index2 = 0;
            } else {
                logOBDData(pidTier2[index2++]);
            }
        }
        //Removed Distance Traveled to Save Bytes (Over 100).


#if USE_MPU6050 //Again this is a gyro sensor, this may be useless.
        if (state & STATE_ACC_READY) {
            processAccelerometer();
        }
#endif


#if ENABLE_DATA_LOG
       
        if (dataSize - lastFileSize >= 1024) { //Creates new save file every 1KB
            flushFile();
            lastFileSize = dataSize;


            // display logged data size


            char buf[7];
            sprintf(buf, "%4uKB", (int)(dataSize >> 10));
            lcd.setFontSize(FONT_SIZE_SMALL);
            lcd.setCursor(92, 7);
            lcd.print(buf);
        }
#endif


        if (errors >= 2) {
            reconnect();
        }
    } //end of loop


//-----------------------------------------------
//SD Card Info and Error Handling


#if ENABLE_DATA_LOG
    bool checkSD()
    {
        Sd2Card card;
        SdVolume volume;
        state &= ~STATE_SD_READY;
        pinMode(SS, OUTPUT);
        if (card.init(SPI_FULL_SPEED, SD_CS_PIN)) {
            const char* type;


            lcd.print("SD"); //Removed Type
            lcd.write(' ');
            if (!volume.init(card)) {
                lcd.print("F2"); //No FAT - F represents failure
                return false;
            }


            uint32_t volumesize = volume.blocksPerCluster();
            volumesize >>= 1; // 512 bytes per block
            volumesize *= volume.clusterCount();
            volumesize >>= 10;


            lcd.print((int)((volumesize + 511) / 1000));
            lcd.print("GB");
        } else {
            lcd.print("SD  ");
            lcd.draw(cross, 16, 16);
            return false;
        }


        if (!SD.begin(SD_CS_PIN)) {
            lcd.print("F3"); //Bad - F represents failure
            return false;
        }


        state |= STATE_SD_READY;
        return true;
    }
#endif


//-----------------------------------------


    void initScreen()
    {
        initLoggerScreen();
    }


//----------------------------------------
//Changed so it would only log Speed and RPM.
//Why is the actual data logger in this program???
//Test to see if this revised code is working.
//Still dont know what this does, since actual datalogging code is in datalogger.h
//However everything is working, and this has been changed from the OG.
//So I really have no idea what its doing.
//I think this just sends the pin info to datalogger.h logData method
private:
    int logOBDData(byte pid)
    {
      int value = 0;
    // send a query to OBD adapter for specified OBD-II pid
    if (readPID(pid, value)) {
        dataTime = millis();
        if (pid == PID_RPM || pid == PID_SPEED) {
            showLoggerData(pid, value);
            // log data to SD card
            logData(0x100 | pid, value);
            //New line can go here, test if all else fails
        }
      }
      return 0; //Indicates Failure
    }


//---------------------------------------------
//Reconnecting Screen


    void reconnect()
    {
#if ENABLE_DATA_LOG
        closeFile();
#endif
        lcd.clear();
        lcd.setFontSize(FONT_SIZE_MEDIUM);
        lcd.print("..."); //Reconnecting - Can leave OBD in while temp away from car.
        startTime = millis();
        state &= ~(STATE_OBD_READY | STATE_ACC_READY);
        state |= STATE_SLEEPING;
        for (uint16_t i = 0; ; i++) {
            if (i == 5) {
                lcd.backlight(false);
                lcd.clear();
            }
            if (init()) {
                int value;
                if (readPID(PID_RPM, value) && value > 0)
                    break;
            }
        }
        state &= ~STATE_SLEEPING;
        fileIndex++;
        setup();
    }


//----------------------------------------------
//Welcome / Start Up Screen
    byte state;


    void showTickCross(bool yes)
    {
        lcd.draw(yes ? tick : cross, 16, 16);
    }
    // screen layout related stuff
    void showStates() //Indicates whether or not vital functions are working.
    {
        lcd.setFontSize(FONT_SIZE_MEDIUM);
        lcd.setCursor(0, 4);
        lcd.print("OBD ");
        showTickCross(state & STATE_OBD_READY);
        lcd.setCursor(0, 6);
        lcd.print("ACC ");
        showTickCross(state & STATE_ACC_READY);
    }


//-------------------------------------------------------------
//Numbers shown when OBD has successfully connected.


    void showLoggerData(byte pid, int value)
    {
        char buf[8];
        switch (pid) {
        case PID_RPM:
            lcd.setCursor(64, 0);
            lcd.setFontSize(FONT_SIZE_XLARGE);
            lcd.printInt((unsigned int)value % 10000, 4);
            break;

        case PID_SPEED:

            if (lastSpeed != value) {
                lcd.setCursor(0, 0);
                lcd.setFontSize(FONT_SIZE_XLARGE);
                lcd.printInt((unsigned int)value % 1000, 3);
                lastSpeed = value;
            }
            break; //End of PID SPEED case.

        case PID_THROTTLE: //Will work depending on Car Specs.
            lcd.setCursor(24, 5);
            lcd.setFontSize(FONT_SIZE_SMALL);
            lcd.printInt(value % 100, 3);
            break;


        case PID_INTAKE_TEMP: //Will work depending on Car Specs.
            if (value < 1000) {
                lcd.setCursor(102, 5);
                lcd.setFontSize(FONT_SIZE_SMALL);
                lcd.printInt(value, 3);
            }
            break;
        }
    }


// Deleted #if USE_MPU6050.
//MPU6050 sensor: Measues Gyro.
//Method within if statement was showGForce.
//This portion is useless.


    void initLoggerScreen()
    {
        lcd.clear();
        lcd.backlight(true);
        lcd.setFontSize(FONT_SIZE_SMALL);
        lcd.setCursor(24, 3);
        lcd.print("kph"); //Speed: Kilometer Per Hour.
        lcd.setCursor(110, 3);
        lcd.print("rpm"); //Engine Rotates Per Min.
        lcd.setCursor(0, 5);
        lcd.print("THR:   %"); //Throttle Postion.
        lcd.setCursor(80, 5);
        lcd.print("AIR:   C"); //Air Tempurature in C.


    }
}; //End of class COBDLogger


static COBDLogger logger;


void setup()
{
    lcd.begin();
    lcd.setFontSize(FONT_SIZE_MEDIUM);
    lcd.print("Nanologger"); //Welcome Screen.


    logger.begin();
    logger.initSender();


#if ENABLE_DATA_LOG
    lcd.setFontSize(FONT_SIZE_MEDIUM);
    lcd.setCursor(0, 2);
    logger.checkSD();
#endif
    logger.setup();
}


void loop()
{
    logger.loop();
}

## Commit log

2026-09-12 added schematic.
    [obd-logger-schematic-v1.fzz]
2026-09-12 Add Schematic Image.
